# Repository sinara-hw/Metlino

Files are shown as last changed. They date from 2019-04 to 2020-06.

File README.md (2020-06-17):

# Metlino
microTCA carrier hub (MCH) Tongue 3 FPGA module with HVDCI and SFP

## Design Files

Design files (schematics, PCB layouts, BOMs) can be found at [Metlino/Releases](https://github.com/sinara-hw/Metlino/releases).

## Wiki

More information can be found on the [wiki](https://github.com/sinara-hw/Metlino/wiki).

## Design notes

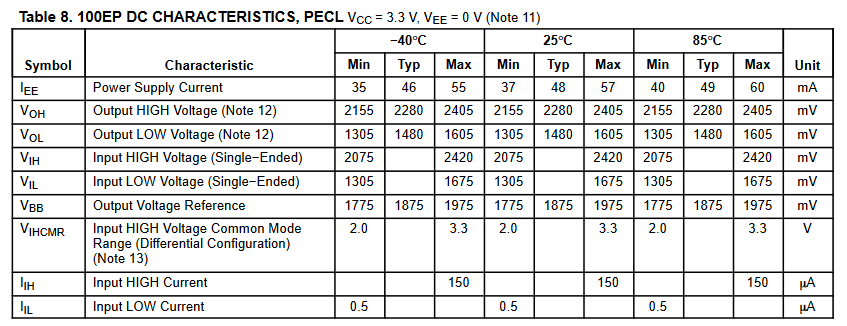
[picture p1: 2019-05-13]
MC100EP_levels.PNG

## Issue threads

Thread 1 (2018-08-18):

Metlino version 0 errata

gkasprow, 2018-08-18:
_From @gkasprow on June 20, 2017 22:15_

- [x] the same as in case of Sayma
- [x] VHDCI  lanes: 0, 8, 16, 24 should go to FPGA clock capable pins
- [x] 0.9V generation - R225+R226=5k1
- [x] add slow start for 12V FMC/RTM
- [x] Zero index everything!
- [x] Assign clock capable pins on FMCs and VHDCIs (cf #217)

_Copied from original issue: sinara-hw/sinara#223_

Closed 2019-04-24.

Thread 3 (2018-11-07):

Metlino Ethernet

gkasprow, 2018-11-07:
@michallgaska

- Replace MAX24287 by M88E1111. This is same IC as KC705 which is already supported by ARTIQ.
- FPGA configures M88E1111 -- no interface with MMC.
- Layout so that uTCA Port0 and SFP can be driven by M88E1111 or by GTH transceiver on FPGA. Use coupling capacitors to choose which.
- Default stuffing and development path is M88E1111. GTH path is for risk mitigation.

sbourdeauducq, 2019-05-18:
>     * Default stuffing and development path is M88E1111. GTH path is for risk mitigation.

Can we get GTH by default? GTH Ethernet is working on Sayma now, and doesn't require fiddling with PHY registers or messy GTH I/O clocking.

gkasprow, 2019-05-19:
sure.done.

Closed 2019-04-24.

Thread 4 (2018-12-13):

Metlino P2P links

gkasprow, 2018-12-13:
For Metlino there are defined  IOSERDES links between main FPGA and Sayma FPGA GTH using second lane of Fat Pipe 1  (Fabrc E). Fabric D is used for GTY-GTY communication and DRTIO. On Sayma  second lane won't be connected to GTY anymore because that GTY would be routed to RTM FPGA.
Once we added WR support, I miss a few LVDS lines to implement all 12 links on Metlino.
The question is if we are ever going to use these lanes? Maybe we should just remove them all. At the moment they are distributed across the banks. Some reside within VHDCI signals, some in SDRAM bank, some among FMC lanes. Clocking such distributed IOSERDES would be tricky.
I have one HR bank connected at the moment to 3.3V, but could switch it to 2.5V to support such additional channel. Some level converters would be needed to support WR I2Cs. On Sayma we could connect the second lane of FatPipe to IOSERDES and gain additional  IOSERDES channel.
The question is - @sbourdeauducq @jordens @hartytp  is it worth to implement them?

jbqubit, 2018-12-13:
@gkasprow It sounds like you're asking multiple things at the same time. AFAICT...
1) If Sayma doesn't support Fabric E then it's not needed on Metlino.
2) If Fabric E support is removed from Metlino do you have enough LVDS lines for WR on Metlino?

gkasprow, 2018-12-13:
Existing Sayma has fabric D and E connected to GTH. Sayma v2 will have one GHT assigned to RTM FPGA and another to fabric D. But I can easily add regular LVDS line to further support it.
After I added WR, I miss one LVDS line to support fabric E on Metlino for 12 slots. But such support would be problematic because individual lanes are scattered between banks with different VCC. I have one HR bank that has just a few signals used for slow control, I can assign them somewhere else and use this one bank (with VCC=2.5V) to fully support fabric E.
What are the plans to use such fabric?

gkasprow, 2018-12-14:
I'm publishing the pdf. Let's do the review. Once we decide what to do with these links, I will update the design.

gkasprow, 2019-04-24:
we don't care about theses links.

Closed 2019-04-24.

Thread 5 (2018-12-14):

Metlino v1.0 schematic review

gkasprow, 2018-12-14:
I published schematics. Still not decided what to do with fabric E, so ignore Bank64 connectivity with Fabric E signals. We will probably use 24pairs of Bank64, supplied from 2.5V to support full  E Fabric.

hartytp, 2018-12-14:
Maybe too late to change this now, but is it worth considering replacing the VHDCI connectors with FMCs to give added flexibility. Users can always combine with an FMC->VHDCI adapter to break out to VHDCI.

Also, if the FP SMAs are too tight then let's replace with MMCXs or similar.

gkasprow, 2018-12-14:
@sinara-hw/wut we don't have that much space to place FMC connectors instead of VHDCI.
We have one FMC but it is faced to backplane.

Closed 2019-04-24.

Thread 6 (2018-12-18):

BOM verification

atcher0, 2018-12-18:
BOM: https://octopart.com/bom-tool/VRV8plDm

Elements out of stock:
- 16251701301000 (Conn Board to Board PL 170 POS 1.5mm Solder RA Thru-Hole) - J13
- TSX-3225 25.0000MF10Z-AC (25 MHz ±10 ppm 18 pF -20 to +85°C Surface Mount Crystal Unit) - Q4

Elements with low avability / near end of life:
- J01151A0921 (Sma Angle Receptacle Pcb (f) 50 Ohm) - J1-J3
- FTS-114-02-L-DV-A (Conn Unshrouded Header HDR 28 POS 1.27mm Solder ST SMD Tube) - J4
- 16241701301000 (Right Angle Male Edge Connector; Through Hole Mount; 170 Way; 1 Row; 1.5mm Pitch) - J12

Additionally, problems from Sayma AMC (sinara-hw/Sayma_AMC#9) apply here.
@gkasprow

gkasprow, 2019-05-11:
8Y-25.000MAAJ-T is again available.
J12/J13 is ordered directly from MFG

Closed 2019-05-11.

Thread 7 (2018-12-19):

check MCH daughter connector

jbqubit, 2018-12-19:
Check with NAT, that MCH Basic v3.5 has connector for daughter boards mounted.

gkasprow, 2019-05-11:
MCH Basic v3.5 has the connector for daughter board assembled.

Closed 2019-05-11.

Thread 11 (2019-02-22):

KU7 alternatives for Metlino >v1.0

jbqubit, 2019-02-22:
In followup to [meeting on 2/18](https://github.com/sinara-hw/sinara/wiki/Sayma-v2-meeting-number-6) there was discussion about FPGA for a future roll of Metlino.

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

@sbourdeauducq provided analysis offline. Reproduced here with his permission.
```
Advantages of A7 (by decreasing importance):
* lower power supply demands and lower PI risk
* Kasli Ethernet code can be reused (NB: I have Ultrascale GTH Ethernet
code but I'm not sure if it works; according to Florent it works on
KCU105, but I can't get it to work on Sayma - it could be broken
hardware since it turns out DRTIO is also flaky on that board's SFP; I
could try another Sayma board tomorrow. My KCU105 doesn't power up anymore.)
* Kasli Grabber code can be reused (implementing CameraLink on
Ultrascale will be a PITA)
* we get another chance at whether this bug appears or not:
https://github.com/m-labs/artiq/issues/1230 anymore (NB: Xilinx should
fix in the next Vivado release a related bug that I reported, this may
or may not get it to work).
* lower power consumption
* lower cost per board

The only problem I can see from the firmware perspective is FPGA timing.
I could check if timing is met with a 12-port DRTIO master on A7-200;
this should be rather quick, but time/funding is very limited.
```

jbqubit, 2019-02-22:
Further comment by @sbourdeauducq

```
Yes. But IMO that re-roll of Metlino won't happen. I get that Greg
doesn't want to throw away most of the existing Metlino design at this
point and use A7, and that's a respectable decision. So it will have to
work correctly with Ultrascale. After this, the only important thing
we'd get with A7 is Grabber support, and it's probably less work to get
the Ultrascale I/Os to behave than redo the whole PCB (or we can just
ignore Grabber support). Then the next version will probably be Zynq-based.
```

Closed 2019-05-11.

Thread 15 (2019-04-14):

backplane transceivers must be clockable by DRTIO

sbourdeauducq, 2019-04-14:
Not the case currently, e.g. quad 224 cannot be reached by the DRTIO clock.

Moving CDR_CLK_CLEAN2 to quad 226 would solve this problem.

gkasprow, 2019-04-24:
added copy of that clock to quad 226

Closed 2019-04-24.

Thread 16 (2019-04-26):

MCH Fabric D and E need at least 1 harness connector in the schematics

marmeladapk, 2019-04-26:
Right now there are many errors caused by this, signals are not recognised as part of the harness.

Could possibly affect other harnesses in the project also.

ed: Placing harness connector solved problems in the same sheet, not in the whole document.

gkasprow, 2019-04-26:
not all signals are routed to FPGA.
I would simply remove the fabric E since we cannot ensure connectivity for all Sayma slots

marmeladapk, 2019-04-26:
Yes, but the point is, that signals are to in the harness and thus are not connected accross schematics:

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

gkasprow, 2019-04-26:
that's strange. Do you have a harness file with the definition? It's required.
There are 2 ways of defining harness. Either you draw harness connector and the file is generated automatically or you define the harness in the file and use nets to keep connectivity. In the second case, the harness entry in the file is not generated automatically.

marmeladapk, 2019-04-26:
I compiled the project straight from the repository. Perhaps some files are missing and weren't created automatically?

marmeladapk, 2019-04-26:
WR_I2C_CTRL on MCH_FPGA_BANKS_64_65.schdoc for example doesn't register all signals MAIN_DCXO_OE, SCL, SDA are not shown as part of the harness.

marmeladapk, 2019-04-26:
On AD17 and higher it is registered correctly.

Closed 2019-04-26.

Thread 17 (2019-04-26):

DRC rules check

marmeladapk, 2019-04-26:
Rules: same comments as in https://github.com/sinara-hw/Sayma_AMC/issues/79
- pin swap by changing schematic pins is enabled

DRC check:
- many off-grid labels, which break this connection for example (I2C_MUX):
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
- extra pin warnings in J12 and J13
- W1 and W11 have unused subparts - typo in designators:
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
- CDR_CLK_CLEAN1 connected to CDR_CLK_CLEAN0 port
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
-floating label (missing jumper?)
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
- suppress missing harness type
- missing negative nets for single ended signals (!?)
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
- multiple harness types caused by different naming (probably error from conversion)

marmeladapk, 2019-05-06:
I2C_SW_ADDR1 shorted to ground due to GND net label
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

marmeladapk, 2019-05-22:
There are still around 100 errors during compilation.

Closed 2019-05-11.

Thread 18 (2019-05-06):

Daughterboard connector

marmeladapk, 2019-05-06:
@gkasprow
- Was communication via SPI with main MCH removed on purpose?
- WRCLK has an additional connector for sending clock signal (J24) -  should Metliuno also have this connector and if not we should check if it doesn't interfere mechanically.

gkasprow, 2019-05-11:
SPI communication is only for ATMEGA update via MCH. Since we are using our own CPU, we don't need it.
@marmeladapk what do you mean by WRCLK and which J24?

marmeladapk, 2019-05-11:
@gkasprow Formerly WR-MCH and J24 on WR_MCH.

gkasprow, 2019-05-11:
In WR-MCH this connector is for PCIe clock only. We won't use PCIe here
And, this connector conflicts with SDRAM.
For this reason, it's easier to add ufl jumper that distributes needed clocks.
There is a use case for WR-MCH and Metlino for the NICA-MCORD project and we will need WR timing distribution but it is needed in AFCK boards only to time-stamp samples. Metlino would serve here as a data concentrator only.
When needed, we can use ufl jumpers.

Closed 2019-05-11.

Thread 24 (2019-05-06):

IC12 missing ground

marmeladapk, 2019-05-06:
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

Under C346

Closed 2019-05-11.

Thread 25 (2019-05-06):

WR_REF_CLK clock should have AC coupling capacitors

atcher0, 2019-05-06:
On WR_REF_CLK clock line AC coupling capacitors should be added and maybe (I am not sure) 50 Ohm resistors (like it is done on IC16 outputs).

Closed 2019-05-11.

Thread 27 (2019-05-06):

Beef up 5V USB to 3.3V LDO

marmeladapk, 2019-05-06:
https://github.com/sinara-hw/Kasli/issues/24

Closed 2019-05-11.

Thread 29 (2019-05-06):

Schematic cosmetics

marmeladapk, 2019-05-06:
- Two DNP notes but one component is marked as DNP in Altium
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
- Mark IC40D N2 and H2 as N/C
- Net P1 (pin G5 in LPC) not connected to anything, remove line?
- SFP - weird DNP text
- DDMTD - cannot open image file - embed images

marmeladapk, 2019-05-29:
- J1 and J2 have hidden designators

Closed 2019-06-22.

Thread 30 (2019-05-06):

RGMII_MDIO multiple net names

marmeladapk, 2019-05-06:
RGMII_MDIO net label is placed on many nets in ETH_PHY schematic.

gkasprow, 2019-05-11:
fixed

Closed 2019-05-11.

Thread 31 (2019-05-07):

Metlino MMC

gkasprow, 2019-05-07:
We asked NAT to develop firmware that allows correct powering of the WR-MCH module from NAT MCH. We could do the same for Metlino. @saleksin takes care of it in Creotech.
Such an approach would let us remotely update the MMC from MCH side and report the presence of Metlino. And of course, enable power supply and Ethernet for it :)
But we would probably have to use the ATMEGA CPU because such chip is used as MMC for NAT MCH mezzanines.

jbqubit, 2019-05-09:
Configuring Metlino to be always-on and updating Metlino MMC via header is fine. Seems like adding a new CPU, tool chain and 3rd party code is a big change for small convenience gains.

gkasprow, 2019-05-10:
This is true providing that we get from NAT info what we need to do to get the power and Ethernet.
NAT offered to give us binaries that we simply burn in the CPU to get power and connectivity.
This, of course, makes life easier for us but would be the only part that is a black box. On the other hand, the NAT MCH is a black box either so personally, I'd choose such an approach. When we make our own MCH board in the future, the power can be enabled by default so such CPU won't be needed.

sbourdeauducq, 2019-05-19:
NAT firmware and software doesn't exactly have a track record of quality, so likely this would be a stopgap at best.
IMO the best way to deal with microTCA in the long term is to take the good things from NAT (basically some hardware: crate, power supply module, fans), and replace the bloated MCH and its crappy firmware with one little board with a STM32 MCU and an integrated Ethernet switch-on-a-chip.
At the same time we can probably ditch most of IPMI and only implement the bare minimum so that the power supply and the fans behave themselves.

gkasprow, 2019-05-19:
@sbourdeauducq we will do so sooner or later.
I got info from NAT that we don't really need to talk to MCH. One need to declare more power that MCH requests from PSU. Ethernet is enabled in an independent way.
Power is on by default.
So we will keep the existing chip and use it for power sequencing nad monitoring.

Closed 2019-05-19.

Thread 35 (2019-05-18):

CLK_200MHz must reach Quad 228

sbourdeauducq, 2019-05-18:
This clock is required for GTH Ethernet.
Currently it is placed in Quad 225 and cannot be properly routed.
We shouldn't need CDR_CLK_CLEAN2 so it can take its place.

gkasprow, 2019-05-19:
I connected it to bank 226 instead of the UFL connectors so now can reach all banks.
the UFLs were connected to bank 225.

Closed 2019-05-19.

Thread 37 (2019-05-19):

external clocking

sbourdeauducq, 2019-05-19:
Do we want to use Metlino as a DRTIO master that distributes an external clock to the DRTIO downstream devices?
If so, we need to send that clock to the FPGA transceivers, and currently the only path that allows this is FRONT_SMA_CLK_IN -> AUX_CLK -> Si5324 in bypass mode -> CDR_CLK_CLEAN.

Does the Si5324 bypass mode have phase noise good performance? If we start developing fancy WR-style clock recovery circuits and use DRTIO to distribute high-quality clocks, we should be careful about this.

hartytp, 2019-05-19:
Weida measured the noise of the Si5324 in bypass mode (I posted the data on one of the issues). It’s not good and we shouldn’t rely on it.

IIRC on Sayma we had a means of getting an ext SMA to an FPGA pin without going through the Si5324 or anything.

What we can potentially do is use the FPGA as a mux to select which clocks goes to the Si5324.

sbourdeauducq, 2019-05-19:
> Weida measured the noise of the Si5324 in bypass mode (I posted the data on one of the issues). It’s not good and we shouldn’t rely on it.

Will it contribute to the noise after going through the transceivers, and CDR at the receiver side?
Does this noise matter on local RTIO signals (e.g. TTLs on VHDCI)?
If not, we are still good.

> What we can potentially do is use the FPGA as a mux to select which clocks goes to the Si5324.

How does that help with the problem of getting a clean external clock to a FPGA transceiver clock pin?

hartytp, 2019-05-19:
Yes, that’s right, the topology I thought we were implementing had the si534 and dcxo outputs going to a mux, which feeds the transceiver. The ext ref SMA goes to the FPGA where it either supplies the reference for the ddmtd pll or it is routed from the FPGA to the si5324 (as a fallback solution).

hartytp, 2019-05-19:
The noise may be okay, I’d have to re-check in-band spurs etc, I’d be more worried about long-term phase drift etc. It’s been a while since I thought about this but iirc the si5324 inbypass mode is still a long way off being  sick buffer and shouldn’t be used as such

sbourdeauducq, 2019-05-19:
OK, then that needs a hardware change to be a on the safe side.

gkasprow, 2019-05-19:
Do I have to change sth in the HW design? In Metlino we have the same direct FPGA input as on Sayma. It's MCX but it's facing the rear MCH module side together with nearby clock output.

sbourdeauducq, 2019-05-20:
Yes, there needs to be an external clock input that can clock all the transceivers, with a low-noise low-drift path. According to @hartytp we should not use the Si5324 as a clock mux. The "external clock input" J10 cannot reach the transceivers (other than with the fabric path which is noisy and not recommended by Xilinx).
Either mux it into CDR_CLK_CLEAN, make a "capacitor selection" circuit to use it instead of the Si5324, or connect it to quad 226 (moving CLK200 to quad 228 on K5/K6 as I suggested earlier) and we can use the FPGA transceiver circuitry as clock mux.
I prefer the latter option. We do not need two copies of CDR_CLK_CLEAN on transceiver pins; GTH clock routing works correctly.

sbourdeauducq, 2019-05-20:
>  In Metlino we have the same direct FPGA input as on Sayma.

Sayma is meant to be used as satellite or repeater and using a CDR clock, whereas Metlino can be the root of the clock tree. How do we define the clock at the root?

hartytp, 2019-05-20:
@sbourdeauduqc what about just locking the dcxo to the external ref in master mode and then using the standard fan out to route that to the transceivers?

hartytp, 2019-05-20:
That’s how we designed this to operate, under the assumption (based on measurements we’ve taken) that the dcxo/ddmtd doesn’t add significant noise/drift

sbourdeauducq, 2019-05-21:
> locking the dcxo to the external ref

How?

hartytp, 2019-05-21:
Ext ref goes to an FPGA io that’s a DDMTD input. Lock the DCXO to that. DCXO already routes to the transceiver.

In fallback mode the FPGA routes that input to an output which drives the Si5325, which drives the transceivers via a mux

sbourdeauducq, 2019-05-21:
And that path through the FPGA won't drift or add noise?
One point of that DDMTD flip-flop circuit was to avoid paths through the FPGA fabric...

hartytp, 2019-05-21:
Aah right id forgotten the plan to use the external DFF. In that case your approach sounds good.

FWIW on the KC705 the fabric DFFs did perform very well. Weida is preparing to test a KC705 with external DFF but so far we have no reason to think it will improve things (may just be limited to transceiver cdr). The external DFF is mainly a protection against ultra scale specific issues

sbourdeauducq, 2019-05-21:
If the external DFF does not improve things then why does the Ultrascale have OBUFDS_GTE3?

hartytp, 2019-05-21:
It may improve things on ultra scale (maybe also on other families) needs testing. FWIW though the performance we got on the KC705 with io dffs was already very good so this is a nice to have rather than a strict requirement so long as the ultra scale can produce the same performance as the Kintex using io dffs.

sbourdeauducq, 2019-05-21:
I would expect *better* performance since we're not going through the noisy fabric. There seems to be a significant difference between transceiver and fabric blocks even before Ultrascale.

hartytp, 2019-05-21:
Let’s hope so. I’ll let you know what Weida finds on the KC705 but ultra scale will have to wait for metlino

gkasprow, 2019-06-29:
I connected clock mux output to bank 226 clk1. CLK200 was moved to bank 228 as @sbourdeauducq suggested.

Closed 2019-06-29.

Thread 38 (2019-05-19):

stop calling everything "WR"

sbourdeauducq, 2019-05-19:
The Si5324 has nothing to do with White Rabbit.
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

What about calling this (Si5324, DCXOs, DDMTD flip-flops, clock switches) the "central PLL" or the "central clocking subsystem"?

sbourdeauducq, 2019-05-19:
Also here:
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
Why is that a "WR" reference clock?
By the way, for clocks to be usable for DRTIO they need to go to transceiver clock inputs, GC pins cannot clock the transceivers well and can only be used to clock local RTIO peripherals. I am not sure what the use case is for this clock, and I don't know if this is a problem or not.

hartytp, 2019-05-19:
Yes we should stop calling things wr as there is much more to the wr stack than a ddmtd pll. I don’t want to bikeshed terminology and will be happy with anything sensible and consistently applied.

hartytp, 2019-05-19:
Was that ref the ddmtd pll reference when Metlino is used as the drtio master?

sbourdeauducq, 2019-05-19:
Why do we need DDMTD when it's used at the master?

hartytp, 2019-05-19:
True if you won’t use the DCXO at all then it’s not needed. On Kasli we’d want it to provide a nice clean clock to the EEMs but Metlino doesn’t have that requirement

gkasprow, 2019-05-19:
OK, now I call this harness Clocking_CTRL and removed "WR" from signal names.

Closed 2019-05-19.

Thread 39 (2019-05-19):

position of GC pins on VHDCI connector

sbourdeauducq, 2019-05-19:
The VHDCI connector is supposed to be used with the VHDCI carrier, but for this purpose the location of GC pins does not seem to match.
For example, pins 1/35 of the VHDCI0 connector do not go to a GC pin of the Ultrascale FPGA on Metlino, but connect to bit 0 of EEM0 on the VHDCI carrier, which is used as a clock signal.

gkasprow, 2019-05-19:
fixed. Now pins 1/35, 2/36, 20/54, 21/55 go to GC
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

sbourdeauducq, 2019-05-20:
On 1.0rc5, FPGA pin of EEM bit0 for...
EEM0: D25/E25
EEM1: C22/C21
EEM2: A25/B25
EEM3: B26/C26
EEM4: W24/W23
....
So far only EEM0 and EEM4 are correct (go to GC pins). Or am I missing out something?

Closed 2019-05-20.

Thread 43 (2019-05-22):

PCB DRC

marmeladapk, 2019-05-22:
Solder mask sliver constraint (IC4)
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

Rules:
- Disable silk to silk clearance constraint?
- Shouldn't minimum annular ring be 0,1mm?
- Add rule about matching length within all differential pair to say 2mm?
- Shouldn MCH_FABRIC_D signals be also length matched (don't know if they are matched in backplane)?

gkasprow, 2019-05-22:
we don't care about GTH links length matching.
Altium calculates annular ring in a strange way. 0.1/0.3mm vias generate errors when the rule is set to more than 50um.

Closed 2019-06-29.

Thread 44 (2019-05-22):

PCB and schematics are not synchronized

marmeladapk, 2019-05-22:

gkasprow, 2019-05-22:
I've just checked. The PCB and schematics are synchronized. repo is up-to-date.
Here is direct Dropbox link https://www.dropbox.com/sh/6qw8ilrs1y406mt/AAAMVxfN1-PtRVFdapyhWw5na?dl=0

marmeladapk, 2019-05-22:
@gkasprow I cloned a fresh repo to double check. I checked with AD 19.1.5. It seems that this may be caused by mismatch between ports and sheet entries, that's visible in compilation errors.

Closed 2019-06-22.

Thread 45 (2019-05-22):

OutputJob

marmeladapk, 2019-05-22:
- Pick and place files are generated twice
- Gerber files are missing some signal layers
- All outputs are generated with imperial units, except for NC drill files

gkasprow, 2019-05-22:
we don't care about units in outputs.

Closed 2019-06-22.

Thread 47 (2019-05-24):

P11 plane

marmeladapk, 2019-05-24:
On P11 there are two separate planes, but both of them are connected to P1V8. Moreover there's a partial split near FMC connector with unknown purpose for me. Shouldn't the part under FMC connector be connected to GND (guessing)?

gkasprow, 2019-06-22:
Fixed. It does not matter if it is 1.8 or GND.

Closed 2019-06-22.

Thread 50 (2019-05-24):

Missing stackup table

marmeladapk, 2019-05-24:
Also make sure to include stackup layer in gerber output layers :)

gkasprow, 2019-06-22:
added to drill drawing

Closed 2019-06-22.

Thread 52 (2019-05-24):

Two holes close to each other

marmeladapk, 2019-05-24:
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

gkasprow, 2019-05-24:
why too close?

marmeladapk, 2019-05-24:
Won't standoff interfere with whatever is supposed to go through the second hole and its nut?

gkasprow, 2019-05-24:
we would use one or another.

Closed 2019-05-24.

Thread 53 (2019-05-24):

Silkscreen

marmeladapk, 2019-05-24:
- Metlino v1.1 instead of rev 1.1?
- Licensed under CERN OHL **v1.2**
- Add voltage rail markings for LEDs (as with test points)
- Designators on components
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

marmeladapk, 2019-05-29:
- J15 designator is outside of PCB
- J14 designator is below vhdci connector

Closed 2019-06-22.

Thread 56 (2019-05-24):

Power integrity check

marmeladapk, 2019-05-24:
ETH-PHY:
- C14 should be between L21 and C438
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
- C305 and C302 shouldn't share ground if possible

FPGA:
- IC2 and IC3 decoupling capaitors connections to P3V3 and ground should be shorter (looks like auto fanout)

CLK
- C514 could have it's own ground connection
- C552 should be between C562 and OSC3 (same with C574 and OSC4)
- Si5324 pin 19&20 missing via? (or vias)

-C502 could be connected to nearby via also

Closed 2019-06-29.

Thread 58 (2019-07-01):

PI analysis after optimization

gkasprow, 2019-07-01:
12V rail. Drop is mainly on MOSFETs.
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
in one place the current density is high on the bottom layer. But we cannot do much. Via currents are fine.
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

gkasprow, 2019-07-01:
1V rail
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

gkasprow, 2019-07-01:
1V5 rail. The DC drop includes also 1V2 LDO so it is fine.
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

gkasprow, 2019-07-01:
1V8
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

gkasprow, 2019-07-01:
3V3 rail. Current density is slightly too high, but on the top layer polygon, so it's fine.
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

gkasprow, 2019-07-01:
VCCINT. Note that the drop includes the coil DCR. In our case the voltage is stabilized under the FPGA.
Current density is high but we cannot really do much with it. It is dominated by buck chip to inductor connection.
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

gkasprow, 2019-07-01:
5V0 rail. It is used to supply 3V3 to clocking circuit via LDO. Simulation assumes that 3.3V LDO was shorted and includes 5V buck coil.
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

gkasprow, 2019-07-01:
P3V3MP
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

jbqubit, 2019-07-08:
Thanks @gkasprow!

Closed 2019-07-01.

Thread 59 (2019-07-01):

Si analysis

gkasprow, 2019-07-01:
Eye diagram @12Gbit 64/66 before optimization of the edge connector vias and before removing NFPs :
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

gkasprow, 2019-07-01:
With NFPs removed and anti-pads increased
red - 2mm anti-pads
light blue - 1.6mm anti-pads
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

gkasprow, 2019-07-01:
Eye diagram for Tx lanes after heavy optimization. There are additional vias and couplig caps
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

gkasprow, 2019-07-02:
SFP loopback test with  SFP cage SI model. Settings at 12Gbit/s, 64/66
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

gkasprow, 2019-07-04:
SiDDR test after optimization finally passes for 1.066GT/s speed.
The detailed report is [here](https://www.dropbox.com/s/k3h3jbyh6trdmn2/DDR_Results_Jul-4-2019_8h-15m.zip?dl=0)

gkasprow, 2019-07-04:
[here](url)

jordens, 2019-07-04:
The trace in https://github.com/sinara-hw/Metlino/issues/59#issuecomment-507141566 looks bad/weird. The difference hovers around 0 for half the UI. Was that an intermediate result or the final one?

gkasprow, 2019-07-04:
It was an intermediate TDR result. The eye diagram looks much better - similar to the last one. The problem is with 0.6mm connector vias because their impedance cannot really be matched and will always be 30Ohm in the best case.

Closed 2019-07-04.

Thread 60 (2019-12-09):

manufacturing and testing status

jbqubit, 2019-12-09:
@marmeladapk When we spoke on 11/27 you said:
- Metlino (qty 4) are stuffed but not yet tested. What is status of testing?
- Metlino-MCH Riser card is on hand. Do you have four of them?
- Front panel for Metlino + MCH is not yet on hand. Has it arrived yet?

jbqubit, 2019-12-16:
@marmeladapk Ping

marmeladapk, 2019-12-18:
- First Metlino card was powered up and works so far. Now we can finish developing our tests. I got info that some of them had been stuffed with LVDS version of Si549 due to CMOS version not being available in that quantity at the time of order).
- We have our own riser card, we got it with our MCH.
- Metlino panel prototype has been fitted, some small adjustments are needed. Afterwards it will be sent to manufacturer (similar timeline to Sayma panels).

kaolpr, 2019-12-19:
I did IBERT test for MGT on one of our cards and they look good.

- IBERT generated for all MGT at 10 Gbps
- Clocks used:
  - MGT228_0 (200 MHz, OSC2)
  - MGT226_0 (125 MHz, OSC3 -> IC16 -> MGT)
- Pins to configured:
  - Main_DCXO_OE (AM11) = 1
  - CLK_SEL (AM12) = 0
- MGT tested with two additional modules:
  - Internaly developed Metlino Tester (basically loopback for AMC signals)
  - [FMC Loopback  by IAM Electronic](http://www.iamelectronic.com/shop/produkt/fpga-mezzanine-card-fmc-loopback-module/)

**Results:**
 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
  - all links are up, besides of Link 19 (MGT 228/3) which was not looped back (Port 0).
  - ost of the links operates flawlessly at PRBS 31b and default settings
  - FMC links (MGT227 2, 3) are experiencing increased BER at PRBS > 9b.

marmeladapk, 2019-12-19:
@kaolpr Did you test FMC links with loopback or with FMC tester?

kaolpr, 2019-12-19:
>     * FMC Loopback  by IAM Electronic

marmeladapk, 2019-12-19:
It's a two layer board without any impedance control. I wouldn't use it for high speed signals.

kaolpr, 2019-12-19:
Yep, but it's configuration-free ;-) and if we use FMC tester there is ADN4604 in the signal path that has data rate limit at 4.25 Gbps.

marmeladapk, 2019-12-19:
What I meant is that increased BER doesn't mean that there's something wrong with Metlino.

kaolpr, 2019-12-19:
Totally agree, but indeed I could express it clearly.

kaolpr, 2019-12-19:
BTW, [similarly to Sayma AMC](https://github.com/sinara-hw/Sayma_AMC/issues/126#issuecomment-533541690), applying  DNP to R13 makes flash operational.

jbqubit, 2019-12-19:
Please post high-resolution photos of front & back side of a stuffed Metlino. Also post another photo showing all the stuffed Metlino arrayed on a table top. This is necessary so Anna can bill for production.

kaolpr, 2020-01-22:
I have just finished testing links in the crate and it looks that all links work.

Metlino was mounted on NAT MCH, did get power supply (we're in contact with NAT to verify that it will work with every NAT MCH) and all backplane links work at 5 Gbps with Sayma AMC. Test was performed using Xilinx IBERT.

I'll do some more testing next week.

jbqubit, 2020-01-22:
> finished testing links

Did you try simultaneous links between rack of Saymas and Metlino at 5 Gbps? Isolated point-to-point isn't sensitive to eg cross-talk.

@kaolpr Please post photos of the stuffed Metlino PCBs' front and back sides.

kaolpr, 2020-01-22:
Haven't tried multiple Saymas yet. I'm planning to do it on Monday.

Where do you want to have these photos posted?

śr., 22 sty 2020, 19:01 użytkownik Joe Britton <notifications@github.com>
napisał:

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

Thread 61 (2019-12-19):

Si549 populated with LVDS not CMOS

jbqubit, 2019-12-19:
> I got info that some of them had been stuffed with LVDS
>version of Si549 due to CMOS version not being available in
>that quantity at the time of order

It's unclear to me the implications of this change. @gkasprow ? Regardless, all Metlino should be stuffed identically to minimize board-to-board variation.

gkasprow, 2019-12-19:
Sure, providing that the oscillators are available. AFAIK they are software-compatible.

jbqubit, 2019-12-20:
@marmeladapk Have they been ordered?

jbqubit, 2020-01-22:
@gkasprow @marmeladapk Can this be closed?

marmeladapk, 2020-01-24:
Let's leave it open and close when they all have the same version of Si549.

sbourdeauducq, 2020-02-04:
The LVDS/CMOS capacitor selection is also wrong on some boards.

jbqubit, 2020-02-04:
What is s/n of board on which you see the problem?

marmeladapk, 2020-02-04:
@jbqubit See https://github.com/sinara-hw/Metlino/wiki/Prototype-reworks

All boards have capacitors mounted for CMOS version.

We plan to switch all boards to LVDS.

marmeladapk, 2020-02-21:
All boards now have LVDS version of Si549. Now I just need to find a moment to swap all capacitors and resistors to LVDS variant.

marmeladapk, 2020-03-04:
All boards have LVDS RC variant now.

Closed 2020-03-04.

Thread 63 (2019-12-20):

SDRAM REFIN is missing ground connection

marmeladapk, 2019-12-20:
Metlino:
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

Sayma:
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

marmeladapk, 2019-12-20:
Adding solder blob fixes SDRAM init and ARTIQ tests.

gkasprow, 2019-12-20:
ah, missing GND!

filipswit, 2021-11-26:
fixed in v1.2

Closed 2021-11-26.

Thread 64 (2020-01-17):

front panel

jbqubit, 2020-01-17:
What is status of Metlino front panel? @marmeladapk Was a prototype ordered? We didn't discuss this at this afternoon's chat.

jbqubit, 2020-01-22:
Ping @marmeladapk

marmeladapk, 2020-01-24:
@jbqubit Prototype panel was ordered, it will probably arrive next week. Wooden prototype panel that we made in house didn't have any glaring issues.

jbqubit, 2020-02-04:
What does the front panel look like?

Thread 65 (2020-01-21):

Too high heatsink

kaolpr, 2020-01-21:
We've assembled Metlino with N.A.T. MCH and tried to put it in the crate ...

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

It looks like the heatsink is too high.

In case of the full-size create it is rather inconvenience that is limiting in some ways, but does not exclude use of Metlino. We can just leave second PSU slot unoccupied.

Unfortunately, in case of R5 crate there is only one PSU slot and MCH slot is next to it so Metlino is mutually exclusive with PSU. Bad.

We can try to use a different heatsink that would have a lower profile, f.e. [ATS-60004-C1-R0](https://eu.mouser.com/datasheet/2/596/TS-60004-C1-R0-1480478.pdf) or [ATS-60002-C1-R0](https://eu.mouser.com/datasheet/2/596/TS-60002-C1-R0-1480509.pdf).

Then we need to be extra cautious with temperature and verify if in an expected use-case we're able to maintain acceptable FPGA temperature.

gkasprow, 2020-01-21:
This heatsink needs machining. I can do that at the WUT.

kaolpr, 2020-01-22:
But what exactly do you mean by machining?
Machining fins won't help as mounting mechanism will still collide.

gkasprow, 2020-01-22:
We can replace it with screws.

Pozdrawiam,
G.Kasprowicz

________________________________
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

kaolpr, 2020-01-22:
We can try that, I'll bring one heatsink to WUT tomorrow.

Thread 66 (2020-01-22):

Components too close to the board edge

kaolpr, 2020-01-22:
Power supply status LEDs, as well as their current setting resistors, are placed too close to the board edge. AMC specification requires at least 1.7mm, whereas diodes are placed as close as 0.988 mm.

Unfortunately, this is not only matter of standard complience. Too low distance causes components to be damaged by crate rails. Below is a photo of LEDs stripped off while sliding module into the crate.

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

gkasprow, 2020-01-22:
let's move them by 0.5mm using hot air gun.

filipswit, 2021-11-26:
Components moved to be min. 1.74mm away

Closed 2021-11-26.

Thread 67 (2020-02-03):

SFP/USB plug collision

sbourdeauducq, 2020-02-03:
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

jbqubit, 2020-02-03:
SMA J1 (FRONT_SMA_CLK_IN) is OK
SMA J2 (SMA_CLK_OUT) collides with SFP J8A

@marmeladapk Consider replacing J2 SMA on prototype hardware with short SMA/SMP connector perpendicular to the PCB.

sbourdeauducq, 2020-02-03:
I think the SMA is fine (but double check) this issue is about the USB programming cable that definitely collides with SFP transceivers.

gkasprow, 2020-02-03:
we cannot do much here. We can move it under SFP so it blocks only one cage. Or move the USB to the backplane side.

jbqubit, 2020-02-03:
Looks to me like that SMA J2 also collides with SFP J8A. No?

jbqubit, 2020-02-03:
Would a very slim micro-USB cable fit? https://www.newegg.com/p/181-02AU-000X8

gkasprow, 2020-02-03:
Can you measure it with calipers?

sbourdeauducq, 2020-02-04:
We can also remove one of the SFPs and replace it with e.g. a SATA connector. What is the use case for having 3?

sbourdeauducq, 2020-02-04:
>  Or move the USB to the backplane side.

No. We do need to be able to reflash and debug Metlino in the crate in an easy manner.

jbqubit, 2020-02-04:
Use case for three SFPs on Metlino is same as on Kasli.

Looks like Amazon has even thinner microUSB cables. https://www.amazon.com/Ribbon-Cable-Degree-Standard-Charging/dp/B0784M2X2C

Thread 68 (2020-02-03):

Si5324 I2C low level is too high

marmeladapk, 2020-02-03:
Si5324 seems not to be able to properly pull SDA low. Tested with FPGA and with MMC talking to Si5324. Other than that Si5324 is reacting properly.

We modified pullup resistors on both sides to 10k. It didn't help.

Screenshot on CPU pullup resistors:

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

Screenshot on I2CMUX4 bus:

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

gkasprow, 2020-02-03:
It looks like one of the ICs was switched to fast mode (push-pull IOs) or MMC has wrong IO mode ( push-pull enabled )

gkasprow, 2020-02-03:
observe SDA before and after the I2C mux

kaolpr, 2020-02-04:
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

@gkasprow These are signals before mux (CPU pullup resistors) and after (I2CMUX4).

marmeladapk, 2020-02-04:
I shorted FPGA bus with Si5324 bus, ACK is still >1V. Both muxes are held in reset.

marmeladapk, 2020-02-04:
Just as a precaution I removed muxes and left only 10kOhm pullup (one per line). Still the same.

marmeladapk, 2020-02-04:
Found it!

FPGA I2C bus is also connected to the CPU (LPC1776).

CPU was configured differently than on Sayma: `IOCON_MODE_INACT` on Metlino, `IOCON_OPENDRAIN_EN` in Sayma. After changing this, Si5324 works in ARTIQ as @sbourdeauducq tested.

Closed 2020-02-04.

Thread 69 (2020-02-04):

photos of Metlino

jbqubit, 2020-02-04:
Please post photos of Metlino front side, back side, front end-on, back end-on.

https://github.com/sinara-hw/Metlino/issues/67#issuecomment-581549618

kaolpr, 2020-02-24:
### 1907180PW0006A0101

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

### 1907180PW0006A0102

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

### 1907180PW0006A0103

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

### 1907180PW0006A0104

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

### 1907180PW0006A0105

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

jbqubit, 2020-02-24:
At long last! Thanks.

akaminska, 2020-04-07:
Unpopulated PCBs
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

jbqubit, 2020-04-07:
Thank you for the PCB photos.

Do you also have Metlino photo with front panel installed? With riser card connecting to NAT MCH?

akaminska, 2020-04-07:
@kaolpr is preparing a photostory on how to integrate Metlino with MCH and attach panel right now. Should appear soon.

akaminska, 2020-04-16:
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

jbqubit, 2020-04-16:
Thanks!!

Closed 2020-02-24.

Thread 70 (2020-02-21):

No P3V3 MP on Metlino #105

marmeladapk, 2020-02-21:
IC41 was dead. After swapping for a new one it works again.

gkasprow, 2020-02-21:
IC41 is Ethernet PHY, not supplied from P3V3MP

gkasprow, 2020-02-22:
@marmeladapk what is IC41? Why it failed?

marmeladapk, 2020-02-24:
@gkasprow I was looking at Sayma schematics not at Metlino. IC7 was dead - buck converter that supplied P3V3_MP. I have no idea why it failed, it had all correct voltages supplied to it and resoldering didn't help.

gkasprow, 2020-02-25:
It could get too high input voltage or reverse biasing

gkasprow, 2020-02-25:
I assume you meant IC18.

gkasprow, 2020-02-25:
IC7 is USB controller on Sayma AMC

marmeladapk, 2020-02-26:
We're talking about Metlino.

Closed 2020-02-21.

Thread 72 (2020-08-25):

Possible typo in I2C mux address

HarryMakes, 2020-08-25:
On page 27 of the latest version of [Metlino's schematic](https://github.com/sinara-hw/Metlino/releases/download/v1.0rc8/Metlino.PDF), there's a table showing all the different ports and addresses of the I2C slave devices. About the default addresses of the two TCA9548A switches, a paragraph reads:

> MMC I2C1, addr 1110 A2 A1 **0**
FPGA I2C and MMC I2C2, addr 1110 A2 A1 **1**
where A2=P2[28], A1=P2[29]
default addr is 0x70 and 0x71

However, the connection for IC43, which is the I2C switch connected to the FPGA_I2C, shows that the address pin 0 is logic 0; similarly, the connection for IC44, which is the other switch connected to MMC_I2C, shows that the address pin 0 is logic 1. Therefore, the paragraph should be corrected as:

> **FPGA I2C** and MMC I2C2, addr 1110 A2 A1 **0**
**MMC I2C1**, addr 1110 A2 A1 **1**
where A2=P2[28], A1=P2[29]
default addr is 0x70 and 0x71

HarryMakes, 2021-09-06:
An update: this typo seems to also affect Sayma_AMC. Issue: https://github.com/sinara-hw/Sayma_AMC/issues/156

filipswit, 2021-11-29:
fixed typo

Closed 2021-11-29.

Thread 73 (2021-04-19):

route Fabric E

gkasprow, 2021-04-19:
At the WUT we are building a large DAQ system for cosmic muon monitoring. We use hundreds of scintillators with [SIPM ](https://hub.hamamatsu.com/jp/en/technical-note/how-sipm-works/index.html)detectors attached on both sides and [FMC-TDC](https://github.com/elhep/FMC_ADC100M_10B_TDC_16cha) boards on top of [AFCK](https://ohwr.org/projects/afck). We will use Metlino for the synchronization and control of 12 AFCK boards as well as very low latency trigger processing. Since DRTIO will use all MGTs, I plan to route LVDS to Fabric E. The new AFCK (Ultra Scale FPGA) which is under development will have an LVDS assembly option for the relevant port. In this way, we would be able to quickly transfer trigger information ( DRTIO time, TDC delay, pulse amplitude) from AFCK to Metlino using IOSERDES. It has the advantage that no CDR is required and the packet can be as short as a few bytes.
The idea is to modify Metlino slightly, without increasing the BOM at all. Samtec has [FSI-family](https://www.samtec.com/products/fsi) 10mm stacking height connectors that do not require mating parts. We simply place pads under FMC connected to Fabric E. When LVDS links are needed, we simply plug a simple FMC module with TVS protection, that links FMC with Fabric E. To further process the triggers, we will use parallel VHDCI cables to cascade more Metlinos and finally to connect to the NICA control system.

jordens, 2021-04-20:
That looks like a really cool connector for mezzanines. Few through holes, reliable registration, good density, and useful stacking height.

gkasprow, 2021-04-20:
they have many options like threaded inserts which you can use to attach screws on both sides. But that takes a lot of space. The main advantage is that it's hard to break them :)

gkasprow, 2021-04-20:
Next thing is to route 16 unused LVCMOS lines  + clock fanout output + 2 LVDS to the similar connector, but sitting below the Mordovia TONGUE 2 clock board. We will modify the Mordovia board to give access to the Metlino to the MLVDS bus. We will be able to distribute clock and 2 MLVDS signals using 1:12 LVDS fanouts. This will give us a backup solution in case of synchronization over DRTIO was not sufficient.

gkasprow, 2021-04-20:
the distance between Metlino and Mordovia is 6.03mm so there is such an option for the connector.
We need:
16 LVTTL signals for MLVDS transceivers
3 diff signals for clocks
2 signals for clock mux control
4 signals for 3V3
at least 8 signals for GND
This gives us 36 signals.
We can use the 40pin FSI-120-06-L-D-AD connector already available in many stores.

gkasprow, 2021-04-20:
@filipswit this would be your next job :)

filipswit, 2021-04-21:
sounds good ;)

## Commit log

2018-12-14 v1.0rc1 schematic review
2019-03-03 remove EE version, added AD19 version
    [CPU_LPC1776.SchDoc, CPU_LPC1776_SUP_PROG.SchDoc, ETH_PHY_RGMII.SchDoc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]
2019-05-07 layout update
    [ETH_PHY_RGMII.SchDoc, MCH_FPGA_Banks_66_68_HP_FMC.SchDoc, PWR_0V9_20A.SchDoc]
2019-05-09 layout update #2
    [SI5324_CDR_WR_oscillators.SchDoc]
2019-05-11 layout #3
    [CPU_LPC1776.SchDoc, DDMTD.SchDoc, FMC_connector.SchDoc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]
2019-05-13 layout update 5
    [ETH_PHY_RGMII.SchDoc, MCH_FPGA_Bank_47_48_67_HP_VHDCI.SchDoc, MCH_FPGA_Banks_224_225_226_227_228.SchDoc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]
2019-05-15 routing 99% done
    [FMC_connector.SchDoc, I2C_MUX.SchDoc, MCH_FPGA_Banks_44_45_46_DDR64.SchDoc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]
2019-05-26 added misisng file to repo
    [SI5324_CDR_DCXO_oscillators.SchDoc]
2019-06-29 all issues fixed
    [MCH_FPGA_Bank_47_48_67_HP_VHDCI.SchDoc, MCH_FPGA_Banks_224_225_226_227_228.SchDoc, MCH_FPGA_Banks_64_65_HR.SchDoc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]
2019-06-30 fixed some PI issues
    [DDMTD.SchDoc, ETH_PHY_RGMII.SchDoc, Metlino_CLK_Distribution.SchDoc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]
2019-07-05 changed BOM and PnP - removed one IC
    [Metlino.PrjPcb]
2019-07-08 Ready to be sent to fab house (but before their checks) Fixed #54 Updated OutJob
    [Metlino.PrjPcb]
2019-10-03 production fixex
    [Metlino.PrjPcb]
2021-11-29 v1.2 sch & pcb update
    [CPU_LPC1776.SchDoc, I2C_MUX.SchDoc, MCH_FPGA_Bank_0_CFG.SchDoc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]
2022-02-10 missing Fabric file
    [Fabric_E_CON.SchDoc]
2022-02-10 adding Fabric file
    [FMC_Metlino_Fabric-Timing.SchDoc, Metlino.PrjPcb]
